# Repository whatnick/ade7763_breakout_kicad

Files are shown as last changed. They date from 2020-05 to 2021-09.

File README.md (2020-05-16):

# ADE7763 Breakout

Minimal Breakout Board for Analog Devices [ADE7763](https://www.analog.com/media/en/technical-documentation/data-sheets/ADE7763.pdf) Enegry Monitor ASIC. This ASIC is a bit dated, but well supported and heavily used in commercial/off-the-shelf
energy metering devices.

## Where to get it

This breakout can be obtained on:
-  [Tindie](https://www.tindie.com/products/whatnick/ade7763-breakout/) 
-  [Oshpark](https://oshpark.com/shared_projects/Y6oIkjGJ)
-  [Aisler](https://aisler.net/p/JMIMWSCE)
-  [PCBWay]()

## Usage

This PCB is designed for breadboard usage and as such should never be connected to LV (240v/120v) power. Use a transformer +
voltage divider mechanism to sample the voltage and a current transformer + multiplier resistor mechanism to sample to current.

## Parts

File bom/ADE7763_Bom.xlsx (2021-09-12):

 | References | manf# | Value | Footprint | Quantity
1 | C3, C5, C11 | TAJA106K010RNJV | 10u | AVX-A | 3
2 | R1, R2, R3, R4 | RT0603FRD071KL | 1K | R0603 | 4
3 | R5, R6 | RT0603FRD07100RL | 100 | R0603 | 2
4 | C4, C6, C12 | GCJ188R71H104KA12D | 100n | C0603 | 3
5 | C7, C8, C9, C10, C13, C14 | C0603C333K5RACTU | 33n | C0603 | 6
6 | C1, C2 | C0603C270K5GACTU | 27p | C0603 | 2
7 | U1 | ADE7763ARSZ | ADE7763ARSZSSOP20 | RS_20-M | 1
8 | Q1 | ABLS-3.579545MHZ-B4-T | 3.58MHz | HC49UP | 1
 |  |  |  |  | 22

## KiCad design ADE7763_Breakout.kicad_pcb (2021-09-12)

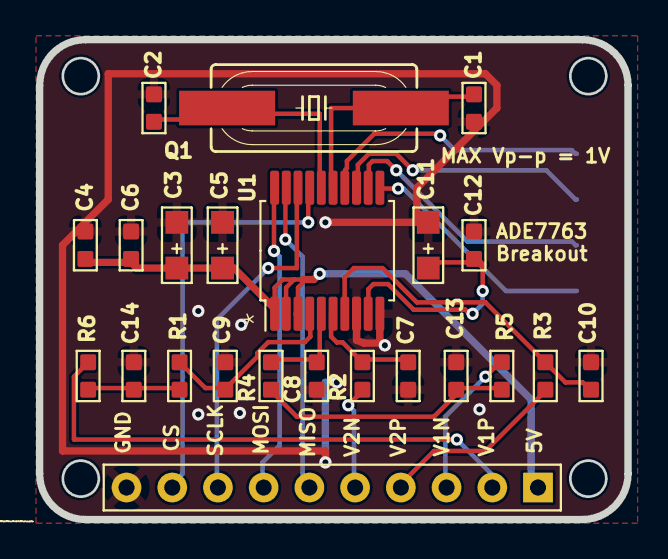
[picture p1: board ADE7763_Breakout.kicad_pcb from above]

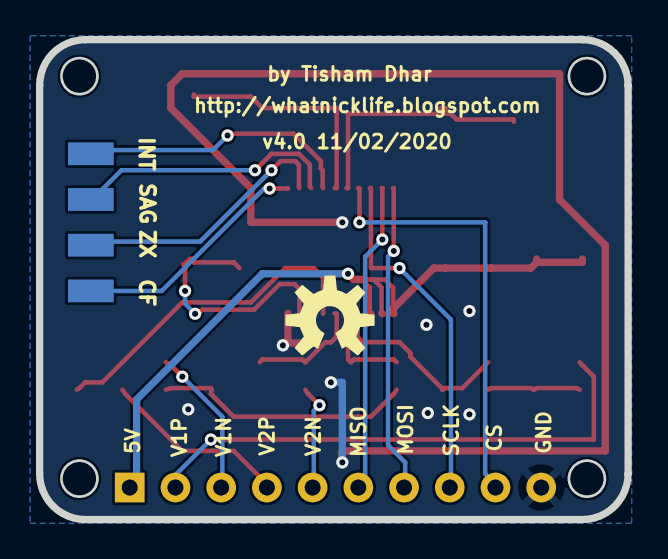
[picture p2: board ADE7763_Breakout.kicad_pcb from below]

Board: 2 copper layers, 32.7 x 26.7 mm, 28 parts (5 on the bottom side), 23 nets.

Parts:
C1, C2: 27p; C0603
C3, C5, C11: 10u; AVX-A
C4, C6, C12: 100n; C0603
C7, C8, C9, C10, C13, C14: 33n; C0603
CF: WIREPADSMD1,27-254; SMD1,27-2,54
INT: WIREPADSMD1,27-254; SMD1,27-2,54
J1: 10p-2.54; H10-2.54
LOGO1: OSHW-LOGOM; OSHW-LOGO-M
Q1: 3.58MHz; HC49UP
R1, R2, R3, R4: 1K; R0603
R5, R6: 100; R0603
SAG: WIREPADSMD1,27-254; SMD1,27-2,54
U1: ADE7763ARSZSSOP20; SSOP-20_5.3x7.2mm_P0.65mm
ZX: WIREPADSMD1,27-254; SMD1,27-2,54

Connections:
5V: C3.+, C4.2, C5.+, C6.2, J1.1, U1.1, U1.2, U1.3
AGND: C1.2, C2.2, C3.-, C4.1, C5.-, C6.1, C7.1, C8.1, C9.1, C10.1, C11.-, C12.1, C13.1, C14.1, J1.10, U1.8, U1.10
CLKIN: C1.1, Q1.1, U1.15
CLKOUT: C2.1, Q1.2, U1.16
CS: J1.9, U1.17
MISO: J1.6, U1.19
MOSI: J1.7, U1.20
unnamed: C13.2, R4.1, R5.1
unnamed: C14.2, R1.1, R6.1
unnamed: INT.1, U1.14
unnamed: C7.2, R2.2, U1.6
unnamed: C8.2, R4.2, U1.5
unnamed: C10.2, R3.2, U1.7
unnamed: C9.2, R1.2, U1.4
unnamed: SAG.1, U1.13
unnamed: C11.+, C12.2, U1.9
unnamed: U1.12, ZX.1
unnamed: CF.1, U1.11
SCLK: J1.8, U1.18
V1N: J1.3, R5.2
V1P: J1.2, R6.2
V2N: J1.5, R2.1
V2P: J1.4, R3.1

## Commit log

2020-02-06 Initial import from Eagle
    [ADE7763_Breakout.kicad_pcb, ADE7763_Breakout.sch]
2020-02-06 Start fixing up imports and sourcing parts
    [ADE7763_Breakout.kicad_pcb, ADE7763_Breakout.sch]
2020-02-10 Complete BOM
    [ADE7763_Bom.xlsx, ADE7763_Breakout.sch]
2020-02-10 Bump version number
    [ADE7763_Breakout.kicad_pcb]
2020-02-11 Prevent bridging across SMD pins
    [ADE7763_Breakout.kicad_pcb]
2020-02-11 Close the loop on Oshpark Board
2020-05-16 Reformat sources of PCB
2021-08-15 Start updating to sync with kicad better
    [ADE7763_Breakout.kicad_pcb, ADE7763_Breakout.kicad_sch]
2021-09-12 Fix PCB for footprint and DRC
    [ADE7763_Bom.xlsx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]
